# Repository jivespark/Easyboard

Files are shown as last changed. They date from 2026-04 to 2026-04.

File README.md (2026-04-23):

# Easyboard
A devboard built for prototyping. It is built to be easy to make quick circuits and test out firmware easily by just plugging this into a laptop and connecting some components. It has a male USB-A connector on the end to make it easy to use without any wires. I built this because I wanted to have a microcontroller that I can just quickly and easily prototye with, and test stuff out for other projects.

Project render:
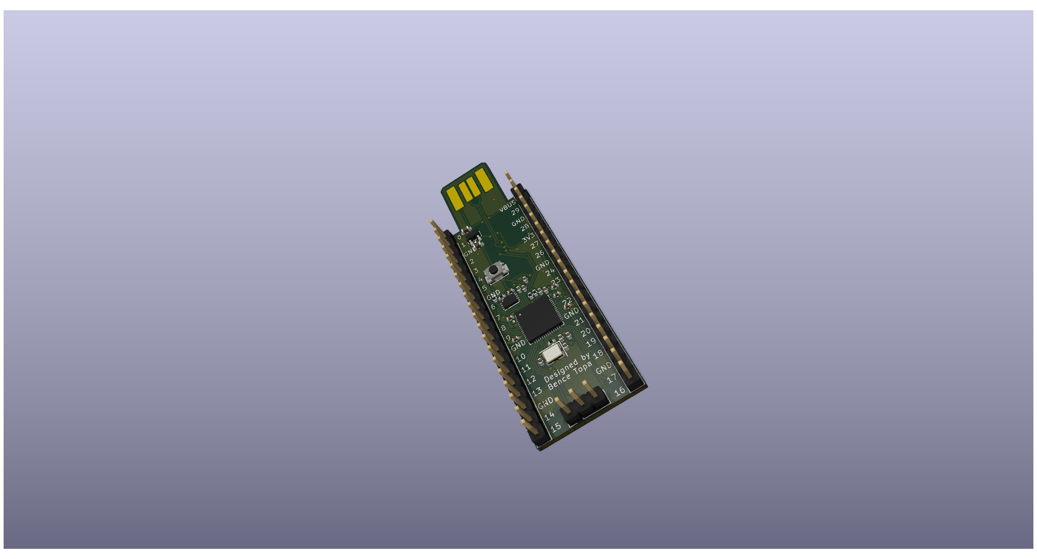
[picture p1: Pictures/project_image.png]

PCB:  
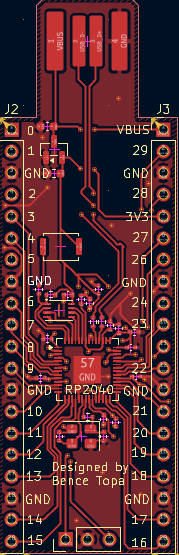
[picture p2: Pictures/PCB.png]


Schematic:
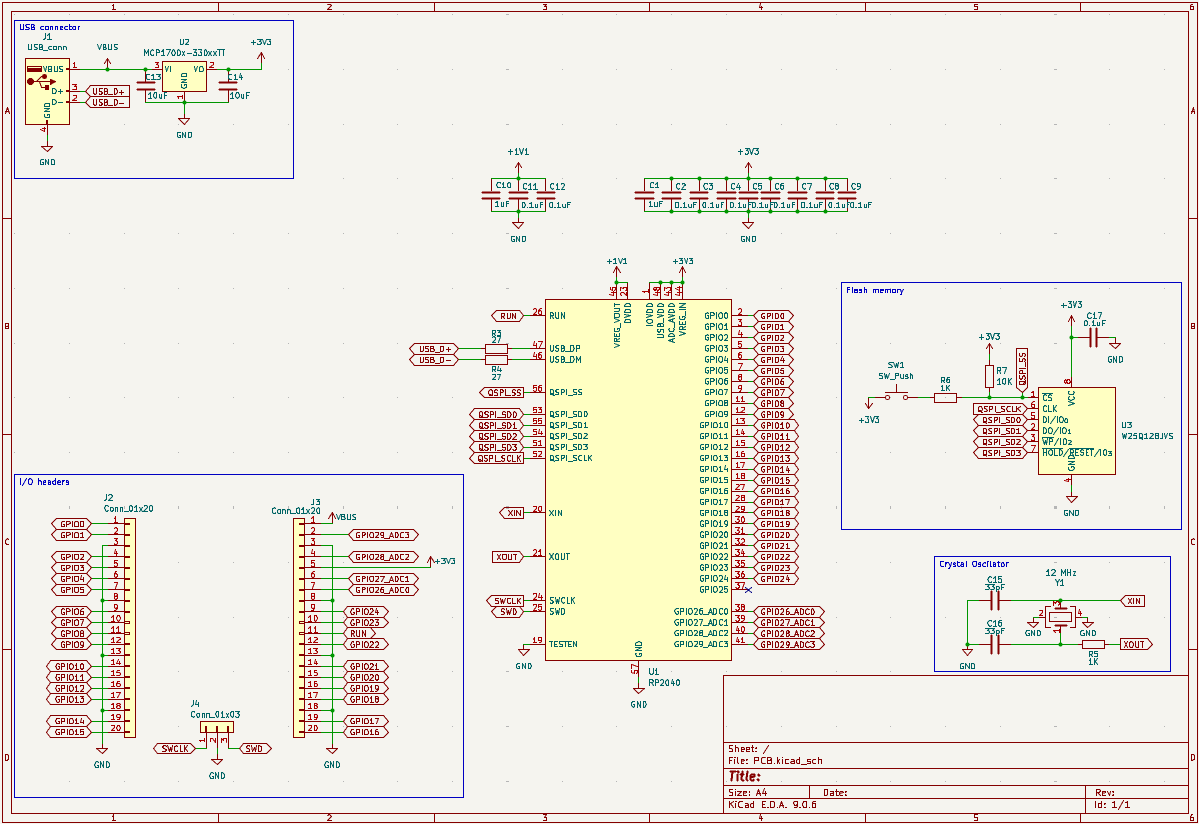
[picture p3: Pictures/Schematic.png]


BOM:
|Name |Purpose |Quantity|Total Cost (USD)|Link |Distributor|Comment |
|---|---|---|---|---|---|---|
|PCB with assembly|The PCBA for the design|1 |45.28 |https://jlcpcb.com|JLCPCB |I couldn't include the proper link, since JLCPCB orders are custom, and don't have a link.|

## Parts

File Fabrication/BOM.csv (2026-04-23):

Id | Designator | Footprint | Quantity | Comment | Supplier and ref
1 | C8,C3,C2,C5,C7,C17,C12,C9,C4,C11,C6 | C_0402_1005Metric | 11 | 0.1uF
2 | J1 | USB_A_PCB_Edge_receptacle | 1 | USB_conn
3 | SW1 | SW_Push_SPST_NO_Alps_SKRK | 1 | SW_Push
4 | J4 | PinHeader_1x03_P2.54mm_Vertical | 1 | Conn_01x03
5 | J2,J3 | PinHeader_1x20_P2.54mm_Vertical | 2 | Conn_01x20
6 | R6,R5 | R_0402_1005Metric | 2 | 1K
7 | U3 | Winbond_USON-8-1EP_3x2mm_P0.5mm_EP0.2x1.6mm | 1 | W25Q128JVS
8 | C15,C16 | C_0402_1005Metric | 2 | 33pF
9 | U2 | SOT-23 | 1 | MCP1700x-330xxTT
10 | R3,R4 | R_0402_1005Metric | 2 | 27
11 | C1,C10 | C_0402_1005Metric | 2 | 1uF
12 | Y1 | Crystal_SMD_3225-4Pin_3.2x2.5mm | 1 | 12 MHz
13 | C14,C13 | C_0603_1608Metric | 2 | 10uF
14 | R7 | R_0402_1005Metric | 1 | 10K
15 | U1 | QFN-56-1EP_7x7mm_P0.4mm_EP3.2x3.2mm | 1 | RP2040

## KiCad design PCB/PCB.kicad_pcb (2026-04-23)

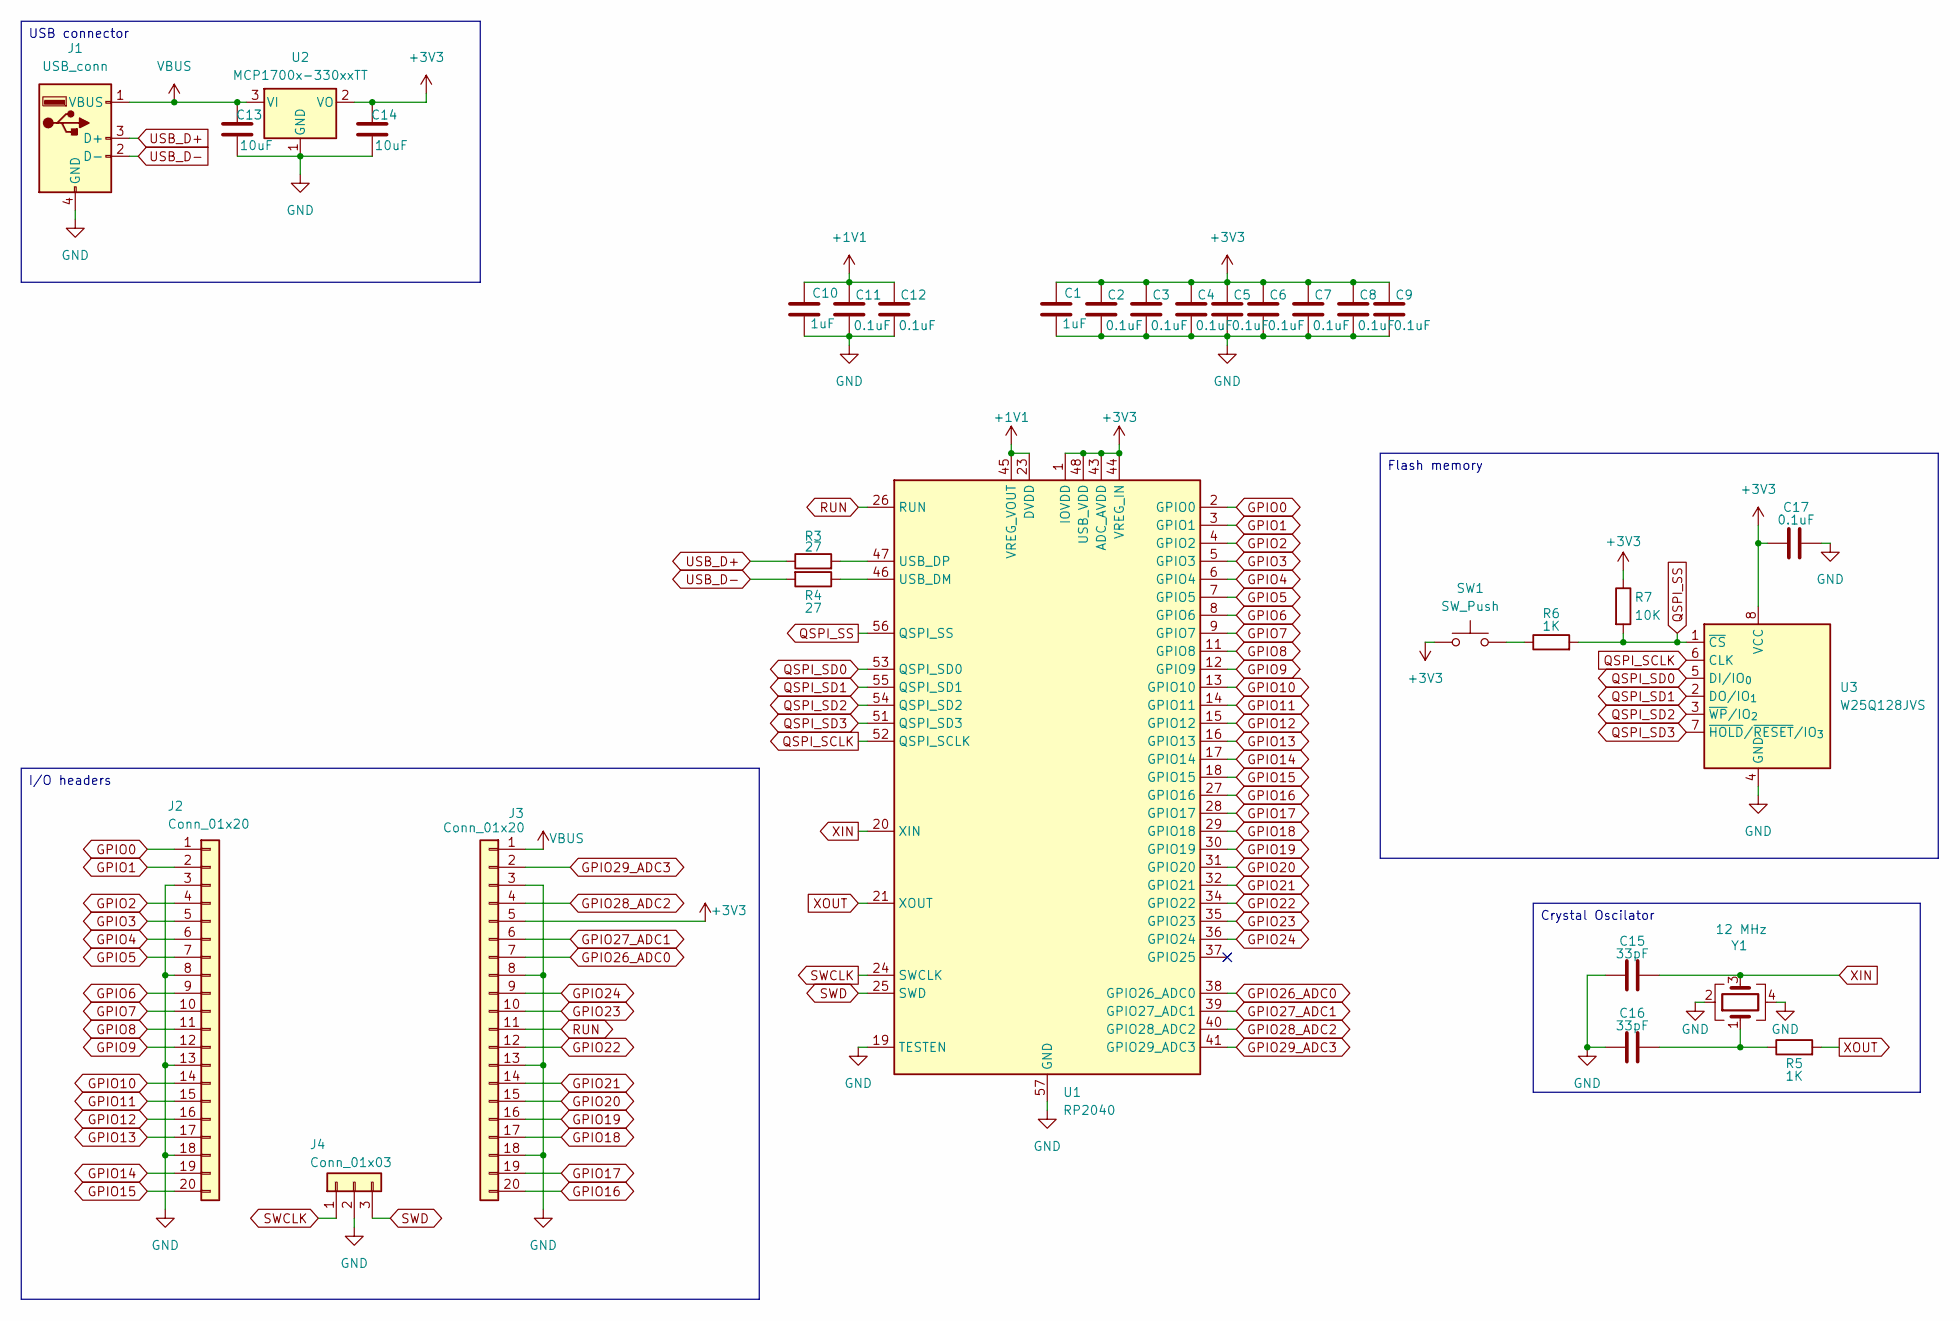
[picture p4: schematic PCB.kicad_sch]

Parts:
C1, C10: 1uF; C_0402_1005Metric
C2, C3, C4, C5, C6, C7, C8, C9, C11, C12, C17: 0.1uF; C_0402_1005Metric
C13, C14: 10uF; C_0603_1608Metric
C15, C16: 33pF; C_0402_1005Metric
J1: USB_conn; USB_A_PCB_Edge_receptacle
J2, J3: Conn_01x20; PinHeader_1x20_P2.54mm_Vertical
J4: Conn_01x03; PinHeader_1x03_P2.54mm_Vertical
R3, R4: 27; R_0402_1005Metric
R5, R6: 1K; R_0402_1005Metric
R7: 10K; R_0402_1005Metric
SW1: SW_Push; SW_Push_SPST_NO_Alps_SKRK
U1: RP2040; QFN-56-1EP_7x7mm_P0.4mm_EP3.2x3.2mm
U2: MCP1700x-330xxTT; SOT-23
U3: W25Q128JVS; Winbond_USON-8-1EP_3x2mm_P0.5mm_EP0.2x1.6mm
Y1: 12 MHz; Crystal_SMD_3225-4Pin_3.2x2.5mm

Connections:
+1V1: C10.1, C11.1, C12.1, U1.23 (DVDD), U1.45 (VREG_VOUT), U1.50 (DVDD)
+3V3: C1.1, C2.1, C3.1, C4.1, C5.1, C6.1, C7.1, C8.1, C9.1, C14.1, C17.1, J3.5, R7.1, SW1.1, U1.1 (IOVDD), U1.10 (IOVDD), U1.22 (IOVDD), U1.33 (IOVDD), U1.42 (IOVDD), U1.43 (ADC_AVDD), U1.44 (VREG_IN), U1.48 (USB_VDD), U1.49 (IOVDD), U2.2 (VO), U3.8 (VCC)
GND: C1.2, C2.2, C3.2, C4.2, C5.2, C6.2, C7.2, C8.2, C9.2, C10.2, C11.2, C12.2, C13.2, C14.2, C15.1, C16.1, C17.2, J1.4 (GND), J2.3, J2.8, J2.13, J2.18, J3.3, J3.8, J3.13, J3.18, J4.2, U1.19 (TESTEN), U1.57 (GND), U2.1 (GND), U3.4 (GND), Y1.2, Y1.4
GPIO0: J2.1, U1.2 (GPIO0)
GPIO1: J2.2, U1.3 (GPIO1)
GPIO2: J2.4, U1.4 (GPIO2)
GPIO3: J2.5, U1.5 (GPIO3)
GPIO4: J2.6, U1.6 (GPIO4)
GPIO5: J2.7, U1.7 (GPIO5)
GPIO6: J2.9, U1.8 (GPIO6)
GPIO7: J2.10, U1.9 (GPIO7)
GPIO8: J2.11, U1.11 (GPIO8)
GPIO9: J2.12, U1.12 (GPIO9)
GPIO10: J2.14, U1.13 (GPIO10)
GPIO11: J2.15, U1.14 (GPIO11)
GPIO12: J2.16, U1.15 (GPIO12)
GPIO13: J2.17, U1.16 (GPIO13)
GPIO14: J2.19, U1.17 (GPIO14)
GPIO15: J2.20, U1.18 (GPIO15)
GPIO16: J3.20, U1.27 (GPIO16)
GPIO17: J3.19, U1.28 (GPIO17)
GPIO18: J3.17, U1.29 (GPIO18)
GPIO19: J3.16, U1.30 (GPIO19)
GPIO20: J3.15, U1.31 (GPIO20)
GPIO21: J3.14, U1.32 (GPIO21)
GPIO22: J3.12, U1.34 (GPIO22)
GPIO23: J3.10, U1.35 (GPIO23)
GPIO24: J3.9, U1.36 (GPIO24)
GPIO26_ADC0: J3.7, U1.38 (GPIO26_ADC0)
GPIO27_ADC1: J3.6, U1.39 (GPIO27_ADC1)
GPIO28_ADC2: J3.4, U1.40 (GPIO28_ADC2)
GPIO29_ADC3: J3.2, U1.41 (GPIO29_ADC3)
unnamed: C16.2, R5.1, Y1.1
unnamed: R6.1, SW1.2
unnamed: R4.1, U1.46 (USB_DM)
unnamed: R3.2, U1.47 (USB_DP)
QSPI_SCLK: U1.52 (QSPI_SCLK), U3.6 (CLK)
QSPI_SD0: U1.53 (QSPI_SD0), U3.5 (DI/IO_{0})
QSPI_SD1: U1.55 (QSPI_SD1), U3.2 (DO/IO_{1})
QSPI_SD2: U1.54 (QSPI_SD2), U3.3 (~WP/IO_{2})
QSPI_SD3: U1.51 (QSPI_SD3), U3.7 (~HOLD/~RESET/IO_{3})
QSPI_SS: R6.2, R7.2, U1.56 (QSPI_SS), U3.1 (~CS)
RUN: J3.11, U1.26 (RUN)
SWCLK: J4.1, U1.24 (SWCLK)
SWD: J4.3, U1.25 (SWD)
USB_D+: J1.3 (D+), R3.1
USB_D-: J1.2 (D-), R4.2
VBUS: C13.1, J1.1 (VBUS), J3.1, U2.3 (VI)
XIN: C15.2, U1.20 (XIN), Y1.3
XOUT: R5.2, U1.21 (XOUT)

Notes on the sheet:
I/O headers
USB connector
Crystal Oscilator
Flash memory

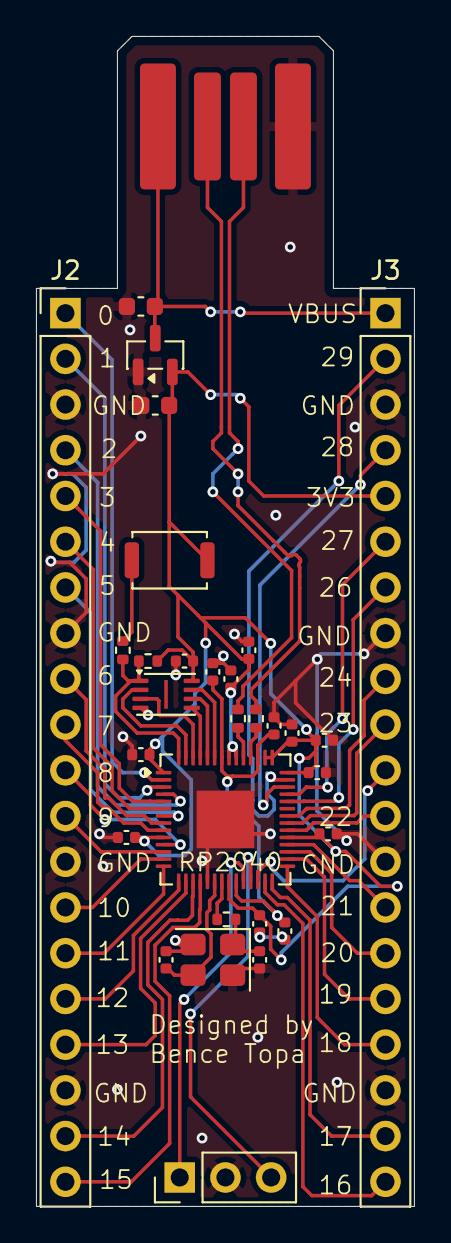
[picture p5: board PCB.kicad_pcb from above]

Board: 2 copper layers, 21.0 x 65.0 mm, 31 parts (0 on the bottom side), 50 nets.

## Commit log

2026-04-23 Added PCB files
    [PCB.kicad_pcb, PCB.kicad_sch, PCB.step]
2026-04-23 Added fabrication files
    [BOM.csv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]
2026-04-23 Added the BOM for Hack club
    [BOM.csv]
